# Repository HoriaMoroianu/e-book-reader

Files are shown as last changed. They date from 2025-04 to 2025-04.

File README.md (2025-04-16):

Moroianu Horia-Valentin

# OpenBook

## Diagrama bloc

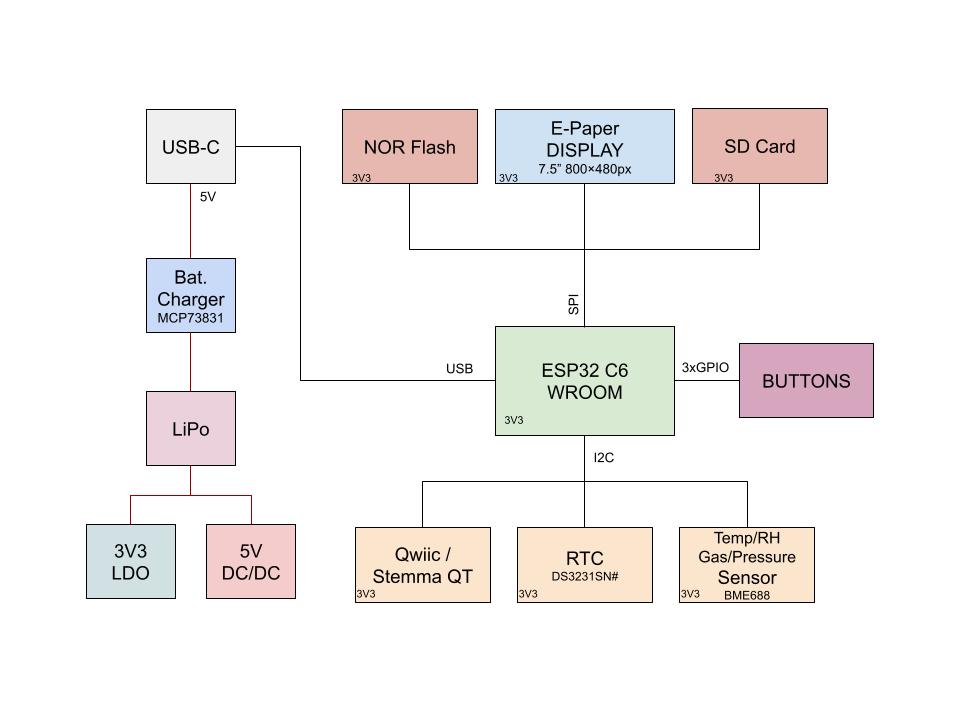
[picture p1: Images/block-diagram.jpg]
Diagrama bloc


## Prezentare Generala

Dispozitivul este construit in jurul microcontrolerului **ESP32-C6-WROOM-1-N8**, o componenta performanta ce ofera conectivitate Wi-Fi 6, Bluetooth 5 LE si o arhitectura RISC-V eficienta energetic. Acesta coordoneaza toate componentele periferice prin magistralele **SPI** si **I2C**.

Pentru masurarea timpului, este integrat un modul **RTC DS3231SN**, conectat prin I2C si semnale auxiliare pentru intreruperi si ceas. Pe aceeasi magistrala I2C functioneaza si senzorul **BME688**, responsabil pentru monitorizarea temperaturii, umiditatii, presiunii si compusilor din aer.

Datele pot fi stocate atat pe un **card SD** (SPI), cat si intr-o memorie **Flash NOR de 64MB**, utilizata pentru firmware. Afisajul grafic este realizat printr-un **ePaper Display**, conectat prin SPI, cu pini de control suplimentari pentru functionare eficienta.

Alimentarea este asigurata de un port **USB-C** cu protectie ESD, in combinatie cu un stabilizator **LDO** de 3.3V. Incarcarea bateriei Li-Po este gestionata de un circuit **MCP73831**, iar starea bateriei este monitorizata cu ajutorul unui **MAX17048**, controlat prin I2C.

Dispozitivul include si un conector **Qwiic/Stemma QT**, facilitand extinderea cu senzori compatibili I2C. Butoanele hardware permit controlul direct al functiilor de IO: resetare, boot si control.

## Conectivitate ESP32-C6

| Pin ESP32-C6 | Componenta Asociata | Functie |
|---|---|---|
| IO0 | RTC - DS3231SN | INT_RTC (Interrupt) |
| IO1 | RTC - DS3231SN | Semnal 32KHz |
| IO2 | SD Card, ePaper, Flash | SPI - MISO |
| IO3 | ePaper Display | EPD BUSY |
| IO4 | SD Card | SPI - CS |
| IO5 | ePaper Display | D/C (Data/Command) |
| IO6 | SD Card, ePaper, Flash | SPI - SCK |
| IO7 | SD Card, ePaper, Flash | SPI - MOSI |
| IO9 | Buton Boot | IO/BOOT |
| IO10 | ePaper Display | SPI - CS |
| IO11 | Flash | SPI - Flash CS |
| IO12 | USB | USB D− |
| IO13 | USB | USB D+ |
| IO15 | Buton CHANGE | IO/CHANGE |
| IO16 | Testpad | UART TX Debugg |
| IO17 | Testpad | UART RX Debugg |
| IO18 | RTC - DS3231SN | RTC Reset |
| IO19 | BME688 | I2C power line |
| IO20 | ePaper Display | EPD Power supply |
| IO21 | RTC, BME688, Qwiic | I2C - SDA |
| IO22 | RTC, BME688, Qwiic | I2C - SCL |
| IO23 | ePaper Display | Reset |
| EN | Buton Reset | IO/RESET |
| 3V3 | Toate modulele | Alimentare 3.3V |
| GND | Toate modulele | Masa |

## BOM

| Componenta | Sursa | Datasheet | Descriere |
| --- | --- | --- | --- |
| XC6220A331MR-G | [Product Page](https://ro.mouser.com/ProductDetail/Torex-Semiconductor/XC6220A331MR-G?qs=AsjdqWjXhJ8ZSWznL1J0gg%3D%3D) | [Datasheet](https://eu.mouser.com/datasheet/2/760/xc6220-3371556.pdf) | LDO regulator |
| W25Q512JVEIQ | [Product Page](https://ro.mouser.com/ProductDetail/Winbond/W25Q512JVEIQ?qs=l7cgNqFNU1jw6svr3at6tA%3D%3D) | [Datasheet](https://ro.mouser.com/datasheet/2/949/Winbond_W25Q512JV_Datasheet-3240039.pdf) | Nor flash |
| USBLC6-2SC6Y | [Product Page](https://ro.mouser.com/ProductDetail/STMicroelectronics/USBLC6-2SC6Y?qs=gNDSiZmRJS%2FOgDexvXkdow%3D%3D) | [Datasheet](https://ro.mouser.com/datasheet/2/389/usblc6_2sc6y-1852505.pdf) | USB ESD prot |
| SI1308EDL-T1-GE3 | [Product Page](https://ro.mouser.com/ProductDetail/Vishay-Semiconductors/SI1308EDL-T1-GE3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) | [Datasheet](https://www.vishay.com/docs/63399/si1308edl.pdf) | MOSFET |
| USB4110-GF-A | [Product Page](https://ro.mouser.com/ProductDetail/GCT/USB4110-GF-A?qs=KUoIvG%2F9IlYiZvIXQjyJeA%3D%3D) | [Datasheet](https://ro.mouser.com/datasheet/2/837/GCT_USB4110_Product_Drawing___20k_cycles-3455479.pdf) | USB C |
| PRT-14417 | [Product Page](https://ro.mouser.com/ProductDetail/SparkFun/PRT-14417?qs=wd5RIQLrsJhgdz%2FpmZ%2F3GQ%3D%3D) | [Datasheet](https://ro.mouser.com/datasheet/2/813/Qwiic_Connector_Datasheet-1223982.pdf) | Qwiic |
| PGB1010603MR | [Product Page](https://ro.mouser.com/ProductDetail/Littelfuse/PGB1010603MR?qs=gu7KAQ731URLg4GSnNNN7Q%3D%3D) | [Datasheet](https://www.littelfuse.com/assetdocs/pulseguard-esd-suppressors-pgb1-datasheet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) | ESD prot diode |
| MBR0530-TP | [Product Page](https://ro.mouser.com/ProductDetail/Micro-Commercial-Components-MCC/MBR0530-TP?qs=KFo7JewZbUECRHkxGanrdg%3D%3D) | [Datasheet](https://ro.mouser.com/datasheet/2/258/MBR0520_MBR0580_SOD123_-2492194.pdf) | Schottky diode |
| MAX17048G+T10 | [Product Page](https://ro.mouser.com/ProductDetail/Analog-Devices-Maxim-Integrated/MAX17048G%2bT10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) | [Datasheet](https://ro.mouser.com/datasheet/2/609/MAX17048_MAX17049-3469099.pdf) | Battery Management |
| FH34SRJ-24S-0.5SH(99) | [Product Page](https://ro.mouser.com/ProductDetail/Hirose-Connector/FH34SRJ-24S-0.5SH99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) | [Datasheet](https://ro.mouser.com/datasheet/2/185/FH34SRJ_24S_0_5SH_99__CL0580_1255_6_99_2DDrawing_0-1615044.pdf) | EPD connector |
| MCP73831-2ACI/MC | [Product Page](https://ro.mouser.com/ProductDetail/Microchip-Technology/MCP73831-2ACI-MC?qs=hH%252BOa0VZEiBneYTVdpuVdg%3D%3D) | [Datasheet](https://ro.mouser.com/datasheet/2/268/MCP73831_Family_Data_Sheet_DS20001984H-3441711.pdf) | Battery controller |
| BME688 | [Product Page](https://ro.mouser.com/ProductDetail/Bosch-Sensortec/BME688?qs=IS%252B4QmGtzzqQoVDscqwx3A%3D%3D) | [Datasheet](https://ro.mouser.com/datasheet/2/783/bst_bme688_fl000-2307034.pdf) | Sensor |
| SD0805S020S1R0 | [Product Page](https://ro.mouser.com/ProductDetail/KYOCERA-AVX/SD0805S020S1R0?qs=jCA%252BPfw4LHbpkAoSnwrdjw%3D%3D) | [Datasheet](https://ro.mouser.com/datasheet/2/40/schottky-3165252.pdf) | Schottky diode |
| B72540T0300K062 | [Product Page](https://ro.mouser.com/ProductDetail/EPCOS-TDK/B72540T0300K062?qs=dEfas%2FXlABK4d0Dv0OnYYg%3D%3D) | [Datasheet](https://www.tdk-electronics.tdk.com/inf/75/db/CTVS_14/Surge_protection_series.pdf) | Varistor |
| ESP32-C6-WROOM-1-N8 | [Product Page](https://ro.mouser.com/ProductDetail/Espressif-Systems/ESP32-C6-WROOM-1-N8?qs=8Wlm6%252BaMh8ST02Gmwp74cw%3D%3D) | [Datasheet](https://ro.mouser.com/datasheet/2/891/Espressif_ESP32_C6_WROOM_1__Datasheet_V0_1_PRELIMI-3239987.pdf) | ESP32 |
| DS3231SN# | [Product Page](https://ro.mouser.com/ProductDetail/Analog-Devices-Maxim-Integrated/DS3231SN?qs=1eQvB6Dk1vhUlr8%2FOrV0Fw%3D%3D) | [Datasheet](https://ro.mouser.com/datasheet/2/609/DS3231-3421123.pdf) | RTC |
| CPH3225A | [Product Page](https://ro.mouser.com/ProductDetail/Seiko-Semiconductors/CPH3225A?qs=3etwrb1wR%252BhUOph6lAO7eg%3D%3D) | [Datasheet](https://ro.mouser.com/datasheet/2/360/Seiko_Instruments_MicroBattery_E_20230330_2024Jan_-3561061.pdf) | Supercap |
| EVQ-P4MB3K | [Product Page](https://ro.mouser.com/ProductDetail/Panasonic/EVQ-P4MB3K?qs=0aNVN3t2tDvlcmyoDZjvlA%3D%3D) | [Datasheet](https://4donline.ihs.com/images/VipMasterIC/IC/PANA/PANA-S-A0000771493/PANA-S-A0000771493-1.pdf) | Buttons |
| BD5229G-TR | [Product Page](https://ro.mouser.com/ProductDetail/ROHM-Semiconductor/BD5229G-TR?qs=4kLU8WoGk0vvnhrrYwdszw%3D%3D) | [Datasheet](https://fscdn.rohm.com/en/products/databook/datasheet/ic/power/voltage_detector/bd52xxg-e.pdf) | Voltage detector |
| 744043680 | [Product Page](https://ro.mouser.com/ProductDetail/Wurth-Elektronik/744043680?qs=PGXP4M47uW6VkZq%252BkzjrHA%3D%3D) | [Datasheet](https://www.we-online.com/components/products/datasheet/744043680.pdf) | Inductor |
| R0402 | [Product Page](https://ro.mouser.com/c/passive-components/resistors/smd-resistors-chip-resistors/?case%20code%20-%20in=0402) | [Datasheet](https://www.vishay.com/docs/28700/mcx0x0xpre.pdf) | Resistor 0402 |
| DMG2305UX-7 | [Product Page](https://ro.mouser.com/ProductDetail/Diodes-Incorporated/DMG2305UX-7?qs=L1DZKBg7t5F%2FNBHrjfxC%252Bg%3D%3D) | [Datasheet](https://www.diodes.com/assets/Datasheets/DMG2305UX.pdf) | MOSFET |
| 112A-TAAR-R03 | [Product Page](https://store.comet.srl.ro/Catalogue/Product/43497/?mark=2) | [Datasheet](https://www.attend.com.tw/data/download/file/112A-TAAR-R03_Spec.pdf) | SD Socket |
| T491B107M006AT | [Product Page](https://ro.mouser.com/ProductDetail/KEMET/T491B107M006AT?qs=U312oeP%2FpiHOgyk6KO2m0g%3D%3D) | [Datasheet](https://ro.mouser.com/datasheet/2/447/KEM_T2005_T491-3316937.pdf) | Tantalum Capacitor |
| LSM0603472V | [Product Page](https://ro.mouser.com/ProductDetail/VCC/LSM0603472V?qs=%252BEew9%252B0nqrBygsW37Z2ISQ%3D%3D) | [Datasheet](https://ro.mouser.com/datasheet/2/423/LSM0603472V_(1)-1379786.pdf) | LED |
| C0402C475K8PACTU | [Product Page](https://ro.mouser.com/c/passive-components/capacitors/ceramic-capacitors/mlccs-multilayer-ceramic-capacitors/multilayer-ceramic-capacitors-mlcc-smd-smt/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) | [Datasheet](https://ro.mouser.com/datasheet/2/447/KEM_C1006_X5R_SMD-3316465.pdf) | Capacitor 0402 |

## Imagini
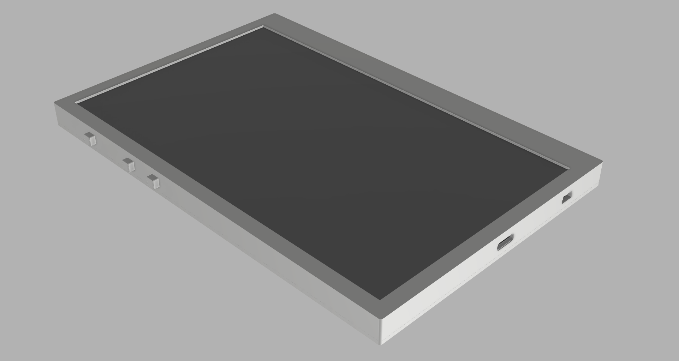
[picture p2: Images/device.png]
device

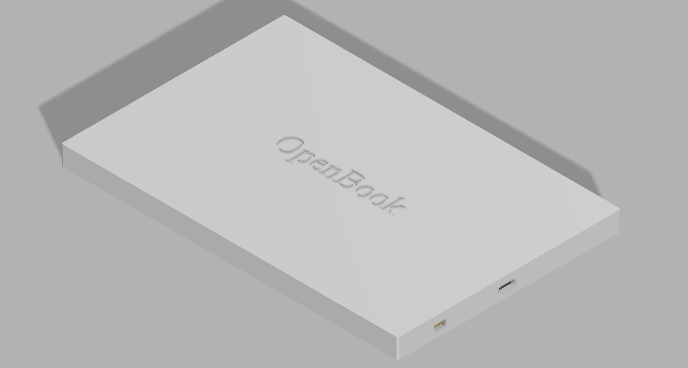
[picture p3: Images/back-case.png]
back case

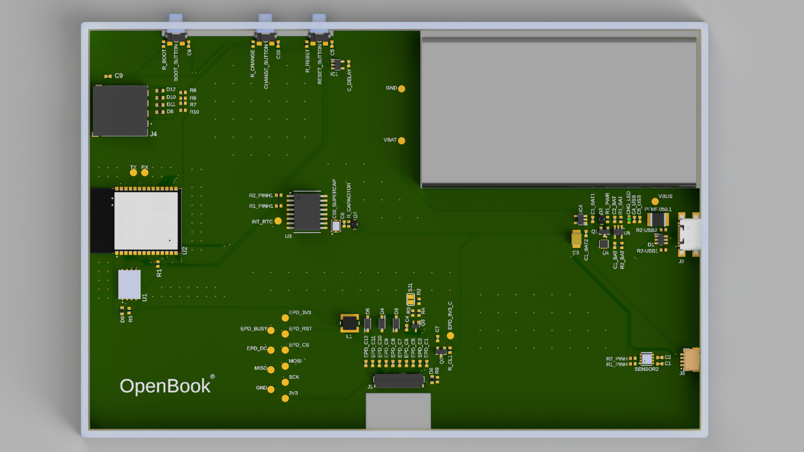
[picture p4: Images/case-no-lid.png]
case no lid

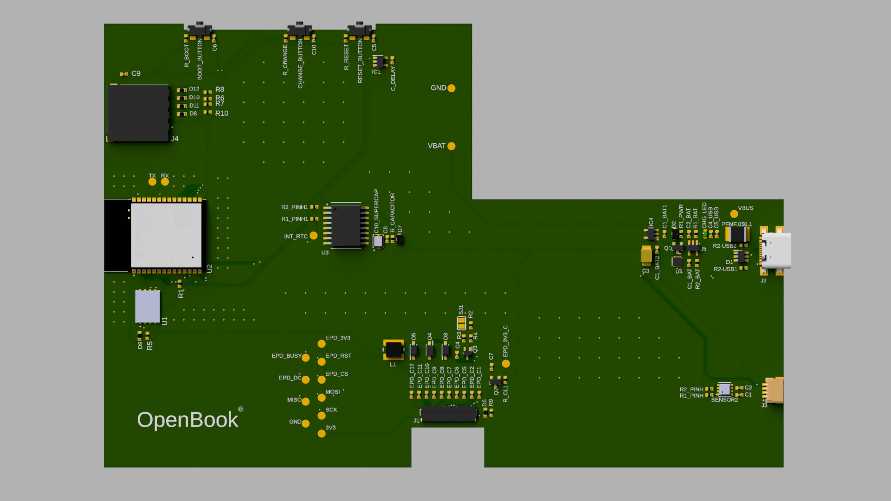
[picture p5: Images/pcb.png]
pcb

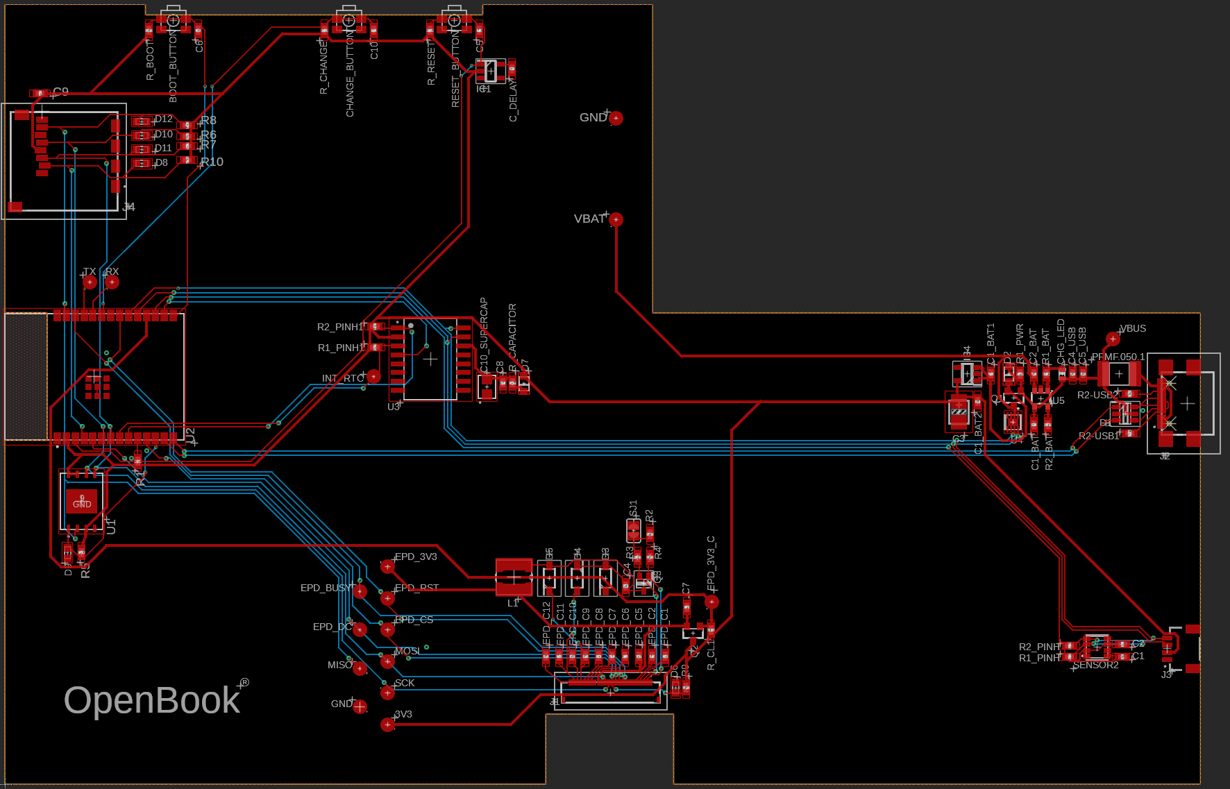
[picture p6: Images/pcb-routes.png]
pcb-routes

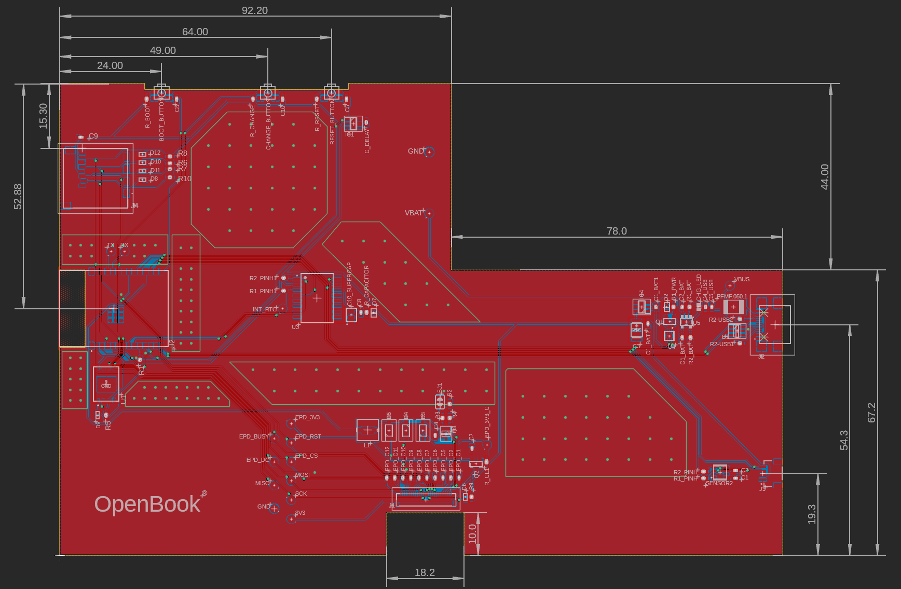
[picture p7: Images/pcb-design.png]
pcb-design


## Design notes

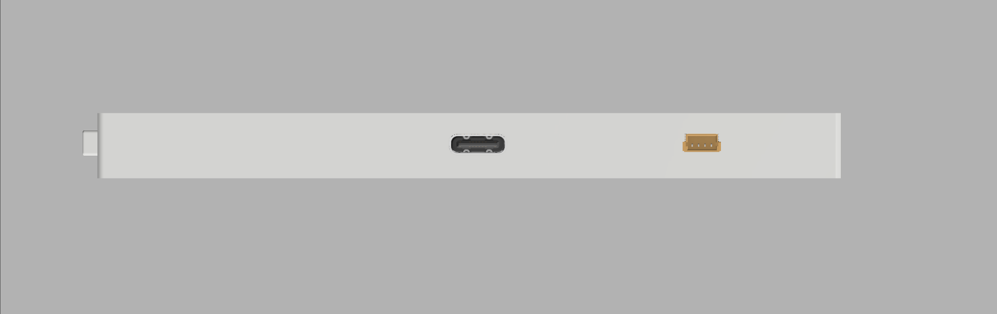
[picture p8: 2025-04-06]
Images/ports.png

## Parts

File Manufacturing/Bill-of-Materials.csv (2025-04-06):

Qty | Value | Device | Package | Parts | Description | ARROW_PART_NUMBER | ARROW_PRICE-STOCK | AVAILABILITY | BME688 | CENTROID_NOT_SPECIFIED | CHECK_PRICES | COPYRIGHT | DATASHEET | DESCRIPTION | DIGIKEY_DESCRIPTION | DIGIKEY_PART_NUMBER | DMG2305UX-7 | HEIGHT | LEAD_FREE | MANUFACTURER_NAME | MANUFACTURER_PART_NUMBER | MCP73831 | MF | MFR_NAME | MOUSER_PART_NUMBER | MOUSER_PRICE-STOCK | MOUSER_TESTING_PART_NUMBER | MOUSER_TESTING_PRICE-STOCK | MP | MPN | PACKAGE | POPULARITY | PREFIX | PRICE | PROD_ID | PURCHASE-URL | ROHS | SD0805S020S1R0 | SNAPEDA_LINK | SPICEMODEL | SPICEPREFIX | TANT | TEMPERATURE_RANGE_HIGH | TEMPERATURE_RANGE_LOW | TP_SIGNAL_NAME | VAL | VALUE
1 |  | ADAFRUIT_LEDCHIP-LED0603 | ADAFRUIT_CHIP-LED0603 | CHG_LED | LED
1 |  | SJ | SJ | SJ1 | SMD solder JUMPER |  |  |  |  |  |  |  |  |  |  |  |  |  |  |  |  |  |  |  |  |  |  |  |  |  |  | 3
1 | 0.1uF/50V | EAGLE-LTSPICE_CC0402 | EAGLE-LTSPICE_C0402 | EPD_C5 | CAPACITOR, European symbol |  |  |  |  |  |  |  |  |  |  |  |  |  |  |  |  |  |  |  |  |  |  |  |  |  |  |  |  |  |  |  |  |  |  | NONE | C
1 | 0.47 | ESP32_WROVER_EAGLE-LTSPICE_RR0402 | ESP32_WROVER_EAGLE-LTSPICE_R0402 | R3 | RESISTOR, European symbol |  |  |  |  |  |  |  |  |  |  |  |  |  |  |  |  |  |  |  |  |  |  |  |  |  |  |  |  |  |  |  |  |  |  | NONE | R
1 | 100k | ESP32_WROVER_EAGLE-LTSPICE_RR0402 | ESP32_WROVER_EAGLE-LTSPICE_R0402 | R1_PWRUSB | RESISTOR, European symbol |  |  |  |  |  |  |  |  |  |  |  |  |  |  |  |  |  |  |  |  |  |  |  |  |  |  |  |  |  |  |  |  |  |  | NONE | R
8 | 100nF | EAGLE-LTSPICE_CC0402 | EAGLE-LTSPICE_C0402 | C1, C2, C4_USB, C6, C8, C9, C10, C_DELAY | CAPACITOR, European symbol |  |  |  |  |  |  |  |  |  |  |  |  |  |  |  |  |  |  |  |  |  |  |  |  |  |  |  |  |  |  |  |  |  |  | NONE | C
1 | 100uF | RCL_CPOL-EUCT3528 | RCL_CT3528 | C3 | POLARIZED CAPACITOR, European symbol |  |  |  |  |  |  |  |  |  |  |  |  |  |  |  |  |  |  |  |  |  |  |  |  |  |  | 0 |  |  |  |  |  |  |  |  | C
16 | 10k | ESP32_WROVER_EAGLE-LTSPICE_RR0402 | ESP32_WROVER_EAGLE-LTSPICE_R0402 | R1, R1_PINH, R1_PINH1, R2_PINH, R2_PINH1, R4, R5, R6, R7, R8, R9, R10, R_BOOT, R_CHANGE, R_CL1, R_RESET | RESISTOR, European symbol |  |  |  |  |  |  |  |  |  |  |  |  |  |  |  |  |  |  |  |  |  |  |  |  |  |  |  |  |  |  |  |  |  |  | NONE | R
1 | 10uF | EAGLE-LTSPICE_CC0402 | EAGLE-LTSPICE_C0402 | C7 | CAPACITOR, European symbol |  |  |  |  |  |  |  |  |  |  |  |  |  |  |  |  |  |  |  |  |  |  |  |  |  |  |  |  |  |  |  |  |  |  | NONE | C
1 | 112A-TAAR-R03_ATTEND | 112A-TAAR-R03_ATTEND | 112ATAARR03ATTEND | J4 | Micro SD Card Socket, Push-Push Type, Top Mount, SMT, H=1.83mm, 10u |  |  |  |  |  |  |  |  | Micro SD Card Socket | Push-Push Type | Top Mount | SMT | H=1.83mm | 10u |  |  |  | 1.9mm |  | ATTEND | 112A-TAAR-R03 ATTEND
1 | 15 | ESP32_WROVER_EAGLE-LTSPICE_RR0402 | ESP32_WROVER_EAGLE-LTSPICE_R0402 | R_CAPACITOR | RESISTOR, European symbol |  |  |  |  |  |  |  |  |  |  |  |  |  |  |  |  |  |  |  |  |  |  |  |  |  |  |  |  |  |  |  |  |  |  | NONE | R
1 | 1uF | EAGLE-LTSPICE_CC0402 | EAGLE-LTSPICE_C0402 | C5 | CAPACITOR, European symbol |  |  |  |  |  |  |  |  |  |  |  |  |  |  |  |  |  |  |  |  |  |  |  |  |  |  |  |  |  |  |  |  |  |  | NONE | C
9 | 1uF/50V | EAGLE-LTSPICE_CC0402 | EAGLE-LTSPICE_C0402 | EPD_C1, EPD_C2, EPD_C6, EPD_C7, EPD_C8, EPD_C9, EPD_C10, EPD_C11, EPD_C12 | CAPACITOR, European symbol |  |  |  |  |  |  |  |  |  |  |  |  |  |  |  |  |  |  |  |  |  |  |  |  |  |  |  |  |  |  |  |  |  |  | NONE | C
1 | 2.2 | ESP32_WROVER_EAGLE-LTSPICE_RR0402 | ESP32_WROVER_EAGLE-LTSPICE_R0402 | R2 | RESISTOR, European symbol |  |  |  |  |  |  |  |  |  |  |  |  |  |  |  |  |  |  |  |  |  |  |  |  |  |  |  |  |  |  |  |  |  |  | NONE | R
1 | 200 | ESP32_WROVER_EAGLE-LTSPICE_RR0402 | ESP32_WROVER_EAGLE-LTSPICE_R0402 | R1_BAT | RESISTOR, European symbol |  |  |  |  |  |  |  |  |  |  |  |  |  |  |  |  |  |  |  |  |  |  |  |  |  |  |  |  |  |  |  |  |  |  | NONE | R
2 | 20V/4.2A/52mO/1.4W | ESP32_WROVER_SPARKFUN-DISCRETESEMI_MOSFET_PCH-DMG2305UX-7 | ESP32_WROVER_SPARKFUN-DISCRETESEMI_SOT23-3 | Q1, Q2 | P-channel MOSFETs |  |  |  |  |  |  |  |  |  |  |  |  |  |  |  |  |  |  |  |  |  |  |  |  |  |  |  |  |  | TRAN-14388 |  |  |  |  |  |  |  |  |  |  |  | 20V/4.2A/52mO/1.4W
1 | 2k | ESP32_WROVER_EAGLE-LTSPICE_RR0402 | ESP32_WROVER_EAGLE-LTSPICE_R0402 | R2_BAT | RESISTOR, European symbol |  |  |  |  |  |  |  |  |  |  |  |  |  |  |  |  |  |  |  |  |  |  |  |  |  |  |  |  |  |  |  |  |  |  | NONE | R
5 | 4.7uF | EAGLE-LTSPICE_CC0402 | EAGLE-LTSPICE_C0402 | C1_BAT, C1_BAT1, C1_BAT2, C2_BAT, C5_USB | CAPACITOR, European symbol |  |  |  |  |  |  |  |  |  |  |  |  |  |  |  |  |  |  |  |  |  |  |  |  |  |  |  |  |  |  |  |  |  |  | NONE | C
1 | 4.7uF/25V | EAGLE-LTSPICE_CC0402 | EAGLE-LTSPICE_C0402 | C4 | CAPACITOR, European symbol |  |  |  |  |  |  |  |  |  |  |  |  |  |  |  |  |  |  |  |  |  |  |  |  |  |  |  |  |  |  |  |  |  |  | NONE | C
2 | 5K1 | ESP32_WROVER_EAGLE-LTSPICE_RR0402 | ESP32_WROVER_EAGLE-LTSPICE_R0402 | R2-USB1, R2-USB2 | RESISTOR, European symbol |  |  |  |  |  |  |  |  |  |  |  |  |  |  |  |  |  |  |  |  |  |  |  |  |  |  |  |  |  |  |  |  |  |  | NONE | R
1 | 744043680IND_4828-WE-TPC_WRE | 744043680IND_4828-WE-TPC_WRE | IND_4828-WE-TPC_WRE | L1 |  |  |  |  |  |  |  | Copyright (C) 2024 Ultra Librarian. All rights reserved. |  |  |  |  |  |  |  |  | 744043680 |  |  | Wurth Electronics |  |  |  |  |  |  |  |  |  |  |  |  |  |  |  |  |  |  |  |  |  | 68uH
1 | BD5229G-TR | BD5229G-TR | SOT95P280X125-5N | IC1 | Voltage Detector with Adjustable Delay Time: CMOS processes are utilized to develop high precision, low current consumption CMOS reset ICs that allow arbitrary setting of the delay time. The extensive lineup includes both Nch Open Drain and CMOS output types in a wide range of detection voltages (from 2.3V to 6.0V, in 0.1V steps), enabling selection of the ideal solution based on customer requirements. In addition, the entire series is of course both lead-free and RoHS-compliant. |  |  |  |  |  |  |  |  | Voltage Detector with Adjustable Delay Time: CMOS processes are utilized to develop high precision | low current consumption CMOS reset ICs that allow arbitrary setting of the delay time. The extensive lineup includes both Nch Open Drain and CMOS output types in a wide range of detection voltages (from 2.3V to 6.0V | in 0.1V steps) | enabling selection of the ideal solution based on customer requirements. In addition | the entire series is of course both lead-free and RoHS-compliant. |  |  |  | 1.25mm |  | ROHM Semiconductor | BD5229G-TR |  |  |  | 755-BD5229G-TR | https://www.mouser.co.uk/ProductDetail/ROHM-Semiconductor/BD5229G-TR?qs=4kLU8WoGk0vvnhrrYwdszw%3D%3D
3 | BUTTON_CUSYOMV1 | BUTTON_CUSYOMV1 | MYBUTTON | BOOT_BUTTON, CHANGE_BUTTON, RESET_BUTTON
1 | CPH3225A | CPH3225A | CAPCP3225X100N | C10_SUPERCAP | Cap 0.011F 3.3V 1210 Flat Check availability |  |  | Not in stock |  |  | https://www.snapeda.com/parts/CPH3225A/Seiko+Instruments/view-part/?ref=eda |  |  | 11 mF (EDLC) Supercapacitor 3.3 V 1210 (3225 Metric) - - |  |  |  |  |  |  |  |  | Seiko Instruments |  |  |  |  |  | CPH3225A |  | 1210 Seiko |  |  | None |  | https://www.snapeda.com/api/url_track_click_mouser/?unipart_id=562593&manufacturer=Seiko Instruments&part_name=CPH3225A&search_term=None |  |  | https://www.snapeda.com/parts/CPH3225A/Seiko+Instruments/view-part/?ref=snap
1 | DS3231SN# | DS3231SN# | SOIC127P1032X265-16N | U3 | Real Time Clock Serial 16-Pin SOIC W T/R Check availability |  |  | In Stock |  |  | https://www.snapeda.com/parts/DS3231SN%23/Analog+Devices/view-part/?ref=eda |  |  | Extremely Accurate I²C-Integrated RTC/TCXO/Crystal |  |  |  |  |  |  |  |  | Analog Devices |  |  |  |  |  | DS3231SN# |  | SOIC-16 Maxim |  |  | None |  | https://www.snapeda.com/api/url_track_click_mouser/?unipart_id=99048&manufacturer=Analog Devices&part_name=DS3231SN#&search_term=None |  |  | https://www.snapeda.com/parts/DS3231SN%23/Analog+Devices/view-part/?ref=snap
1 | ESP32-C6-WROOM-1-N8 | ESP32-C6-WROOM-1-N8 | XCVR_ESP32-C6-WROOM-1-N8 | U2 | Check availability |  |  | In Stock |  |  | https://www.snapeda.com/parts/ESP32-C6-WROOM-1-N8/Espressif+Systems/view-part/?ref=eda |  |  | Multiprotocol Modules ESP32-C6 module | Wi-Fi 6 in 2.4 GHz band | Bluetooth 5 | Zigbee 3.0 and Thread. ESP34-WROOM Compatible - ENGINEERING SAMPLE |  |  |  |  |  |  |  |  | Espressif Systems |  |  |  |  |  | ESP32-C6-WROOM-1-N8 |  | None |  |  | None |  |  |  |  | https://www.snapeda.com/parts/ESP32-C6-WROOM-1-N8/Espressif+Systems/view-part/?ref=snap
1 | ESP32C6_VARISTORCN1812 | ESP32C6_VARISTORCN1812 | ESP32C6_VARISTOR_CT/CN1812 | PFMF.050.1 | VARISTOR |  |  |  |  |  |  |  |  |  |  |  |  |  |  |  |  |  |  |  |  |  |  |  |  |  |  | 0
2 | ESP32_WROVER_AVX---SD0805S020S1R0_AVX_SD0805S020S1R0_0_0AVX_SD0805S020S1R0_0_0 | ESP32_WROVER_AVX---SD0805S020S1R0_AVX_SD0805S020S1R0_0_0AVX_SD0805S020S1R0_0_0 | ESP32_WROVER_AVX---SD0805S020S1R0_AVX_SD0805S020S1R0_0 | D2, D7 | Schottky Barrier Rectifier Diode |  |  |  |  | No |  |  | http://datasheets.avx.com/schottky.pdf |  | DIODE SCHOTTKY 20V 1A 0805 | 478-7800-1-ND |  |  | yes |  |  |  | AVX |  | 581-SD0805S020S1R0 |  |  |  |  |  | 0805 (2012 metric) |  | D |  |  |  | yes |  |  |  |  |  | +125°C | -55°C
1 | ESP32_WROVER_BME680_BME680 | ESP32_WROVER_BME680_BME680 | ESP32_WROVER_BME680_PSON80P300X300X100-8N | SENSOR2 | Integrated Environmental Unit |  |  | Unavailable |  |  |  |  |  | Integrated Environmental Unit |  |  |  |  |  |  |  |  | Bosch Sensortec |  |  |  |  |  | BME680 |  | LGA-8 Bosch Tools |  |  | None
1 | ESP32_WROVER_SPARKFUN-IC-POWER_MCP73831 | ESP32_WROVER_SPARKFUN-IC-POWER_MCP73831 | ESP32_WROVER_SPARKFUN-IC-POWER_SOT23-5 | U5 | MCP73831T Li-Ion, Li-Pol Controller |  |  |  |  |  |  |  |  |  |  |  |  |  |  |  |  |  |  |  |  |  |  |  |  |  |  |  |  |  | IC-09995
1 | FH34SRJ-24S-0.5SH_99_ | FH34SRJ-24S-0.5SH_99_ | FH34SRJ24S05SH99 | J1 | (0.50mm) Surface Mount, Right Angle |  |  |  |  |  |  |  |  | 24 Position FFC | FPC Connector Contacts | (0.50mm) Surface Mount | Right Angle |  |  |  | 1.1mm |  | Hirose | FH34SRJ-24S-0.5SH(99) |  |  |  | 798-FH34SRJ24S05SH99 | https://www.mouser.co.uk/ProductDetail/Hirose-Connector/FH34SRJ-24S-0.5SH99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
1 | MAX17048G+T10 | MAX17048G+T10 | SON50P200X200X80-9N | U4 | Check availability |  |  | In Stock |  |  | https://www.snapeda.com/parts/MAX17048G+T10/Analog+Devices/view-part/?ref=eda |  |  | 3µA 1-Cell/2-Cell Fuel Gauge with ModelGauge |  |  |  |  |  |  |  |  | Analog Devices |  |  |  |  |  | MAX17048G+T10 |  | TDFN-8 Maxim |  |  | None |  | https://www.snapeda.com/api/url_track_click_mouser/?unipart_id=329239&manufacturer=Analog Devices&part_name=MAX17048G+T10&search_term=None |  |  | https://www.snapeda.com/parts/MAX17048G+T10/Analog+Devices/view-part/?ref=snap
3 | MBR0530 | MBR0530 | SOD3716X135N | D3, D4, D5 | ON SEMICONDUCTOR - MBR0530 - DIODE, SCHOTTKY, 0.5A, 30V, SOD-123 |  |  | In Stock |  |  | https://www.snapeda.com/parts/MBR0530/Onsemi/view-part/?ref=eda |  |  | Diode Schottky 30 V 500mA Surface Mount SOD-123 |  |  |  |  |  |  |  |  | ON Semiconductor |  |  |  |  |  | MBR0530 |  | SOD-123-2 ON Semiconductor |  |  | None |  | https://www.snapeda.com/api/url_track_click_mouser/?unipart_id=179458&manufacturer=ON Semiconductor&part_name=MBR0530&search_term=None |  |  | https://www.snapeda.com/parts/MBR0530/Onsemi/view-part/?ref=snap
6 | PGB1010603MR | PGB1010603MR | DIOC1608X36N | D6, D8, D9, D10, D11, D12 | Check availability |  |  | In Stock |  |  | https://www.snapeda.com/parts/PGB1010603MR/Littelfuse/view-part/?ref=eda |  |  | 150V (Typ) Clamp - Ipp Tvs Diode Surface Mount 0603 (1608 Metric) |  |  |  |  |  |  |  |  | Littelfuse Inc. |  |  |  |  |  | PGB1010603MR |  | 0603 Littelfuse Inc. |  |  | None |  | https://www.snapeda.com/api/url_track_click_mouser/?unipart_id=5659453&manufacturer=Littelfuse Inc.&part_name=PGB1010603MR&search_term=None |  |  | https://www.snapeda.com/parts/PGB1010603MR/Littelfuse/view-part/?ref=snap
1 | QWIIC_RIGHT_ANGLE | QWIIC_CONNECTORJS-1MM | JST04_1MM_RA | J3 | SparkFun I2C Standard Qwiic Connector |  |  |  |  |  |  |  |  |  |  |  |  |  |  |  |  |  |  |  |  |  |  |  |  |  |  |  |  |  | CONN-13694 |  |  |  |  |  |  |  |  |  |  |  | QWIIC_RIGHT_ANGLE
1 | SAMACSYS_PARTS_USB4110-GF-A | SAMACSYS_PARTS_USB4110-GF-A | SAMACSYS_PARTS_USB4110GFA | J2 | CONN USB 2.0 TYPE-C R/A SMT |  |  |  |  |  |  |  |  | CONN USB 2.0 TYPE-C R/A SMT |  |  |  | 3.26mm |  | GCT (GLOBAL CONNECTOR TECHNOLOGY) | USB4110-GF-A |  |  |  | 640-USB4110-GF-A | https://www.mouser.co.uk/ProductDetail/GCT/USB4110-GF-A?qs=KUoIvG%2F9IlYiZvIXQjyJeA%3D%3D
1 | SI1308EDL-T1-GE3 | SI1308EDL-T1-GE3 | SOT65P210X110-3N | Q3 | MOSFET N-Ch 30V 1.5A TrenchFET SC70 Vishay Si1308EDL-T1-GE3 N-channel MOSFET Transistor, 1.5 A, 30 V, 3-Pin SC-70 |  |  | In Stock |  |  | https://www.snapeda.com/parts/SI1308EDL-T1-GE3/Vishay+Siliconix/view-part/?ref=eda |  |  | Si1308EDL-T1-GE3 N-channel MOSFET Transistor | 1.5 A | 30 V | 3-Pin SC-70 | Siliconix / Vishay SI1308EDL-T1-GE3 |  |  |  |  |  |  |  |  | Vishay Siliconix |  |  |  |  |  | SI1308EDL-T1-GE3 |  | SOT-323 Vishay Semiconductor |  |  | None |  | https://www.snapeda.com/api/url_track_click_mouser/?unipart_id=274603&manufacturer=Vishay Siliconix&part_name=SI1308EDL-T1-GE3&search_term=None |  |  | https://www.snapeda.com/parts/SI1308EDL-T1-GE3/Vishay+Siliconix/view-part/?ref=snap
17 | TPTP20R | TPTP20R | TP20R | TP1, TP2, TP3, TP4, TP5, TP6, TP7, TP8, TP9, TP10, TP11, TP12, TP13, TP14, TP15, TP16, TP17 | Test pad |  |  |  |  |  |  |  |  |  |  |  |  |  |  |  |  |  |  |  |  |  |  |  |  |  |  | 2
1 | USBLC6-2SC6Y | USBLC6-2SC6Y | SOT95P280X145-6N | D1 | Low Cap. ESD Protection Auto SOT-23-6 STMicroelectronics USBLC6-2SC6Y, Dual Uni-Directional TVS Diode Array, 6-Pin SOT-23 |  |  | In Stock |  |  | https://www.snapeda.com/parts/USBLC6-2SC6Y/STMicroelectronics/view-part/?ref=eda |  |  | 17V Clamp 5A (8/20µs) Ipp Tvs Diode Surface Mount SOT-23-6 |  |  |  |  |  |  |  |  | STMicroelectronics |  |  |  |  |  | USBLC6-2SC6Y |  | SOT-23-6 STMicroelectronics |  |  | None |  |  |  |  | https://www.snapeda.com/parts/USBLC6-2SC6Y/STMicroelectronics/view-part/?ref=snap
1 | W25Q512JVEIQ | W25Q512JVEIQ | SON127P600X800X80-9N | U1 | Check availability |  |  | In Stock |  |  | https://www.snapeda.com/parts/W25Q512JVEIQ/Winbond+Electronics/view-part/?ref=eda |  |  | FLASH - NOR Memory IC 512Mb (64M x 8) SPI - Quad I/O 133 MHz 8-WSON (8x6) |  |  |  |  |  |  |  |  | Winbond Electronics |  |  |  |  |  | W25Q512JVEIQ |  | Package |  |  | None |  |  |  |  | https://www.snapeda.com/parts/W25Q512JVEIQ/Winbond+Electronics/view-part/?ref=snap
1 | XC6220A331MR-G | XC6220A331MR-G | SOT95P280X120-5N | IC4 | LDO Voltage Regulators |  |  |  |  |  |  |  |  | LDO Voltage Regulators |  |  |  | 1.2mm |  | Torex | XC6220A331MR-G |  |  |  | 865-XC6220A331MR-G | https://www.mouser.co.uk/ProductDetail/Torex-Semiconductor/XC6220A331MR-G?qs=AsjdqWjXhJ8ZSWznL1J0gg%3D%3D

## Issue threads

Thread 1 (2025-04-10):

Trebuie adaugate informatii in README.md

branistecristian, 2025-04-10:
**README** trebuie să conțină minim:
- O diagramă bloc cu toate componentele proiectului vostru și cum sunt ele legate (model aici).
- Un **BOM** (Bill Of Materials) sub formă de tabel cu componentele sau modulele pe care le-ați folosit și link-uri către locul de unde le puteți procura (folosiți Mouser și Comet) și link către datasheet-ul lor.
- Descrierea în detaliu a funcționalității hardware (ce module, componente, senzori, etc. ați folosit, prin ce interfețe se leagă la microcontroller-ul vostru, specificații de comunicație, procesare, calcule de consum de energie și orice altceva considerați relevant).
- Descrieți în detaliu ce pini ai **ESP32-C6** sunt folosiți pentru fiecare componentă și de ce.
- Orice altceva considerați că ar fi relevant pentru review (design log, imagini cu randări ale PCB-ului, așezarea componentelor în carcasă etc.).

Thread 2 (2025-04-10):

Grosime PCB

branistecristian, 2025-04-10:
### PCB-ul este configurat in prezent cu o grosime de **1.6mm**, insa proiectul necesita o grosime de **1.0mm** pentru a se potrivi corect in carcasa

## Referinte
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

HoriaMoroianu, 2025-04-16:
Eroare la export

Closed 2025-04-16.

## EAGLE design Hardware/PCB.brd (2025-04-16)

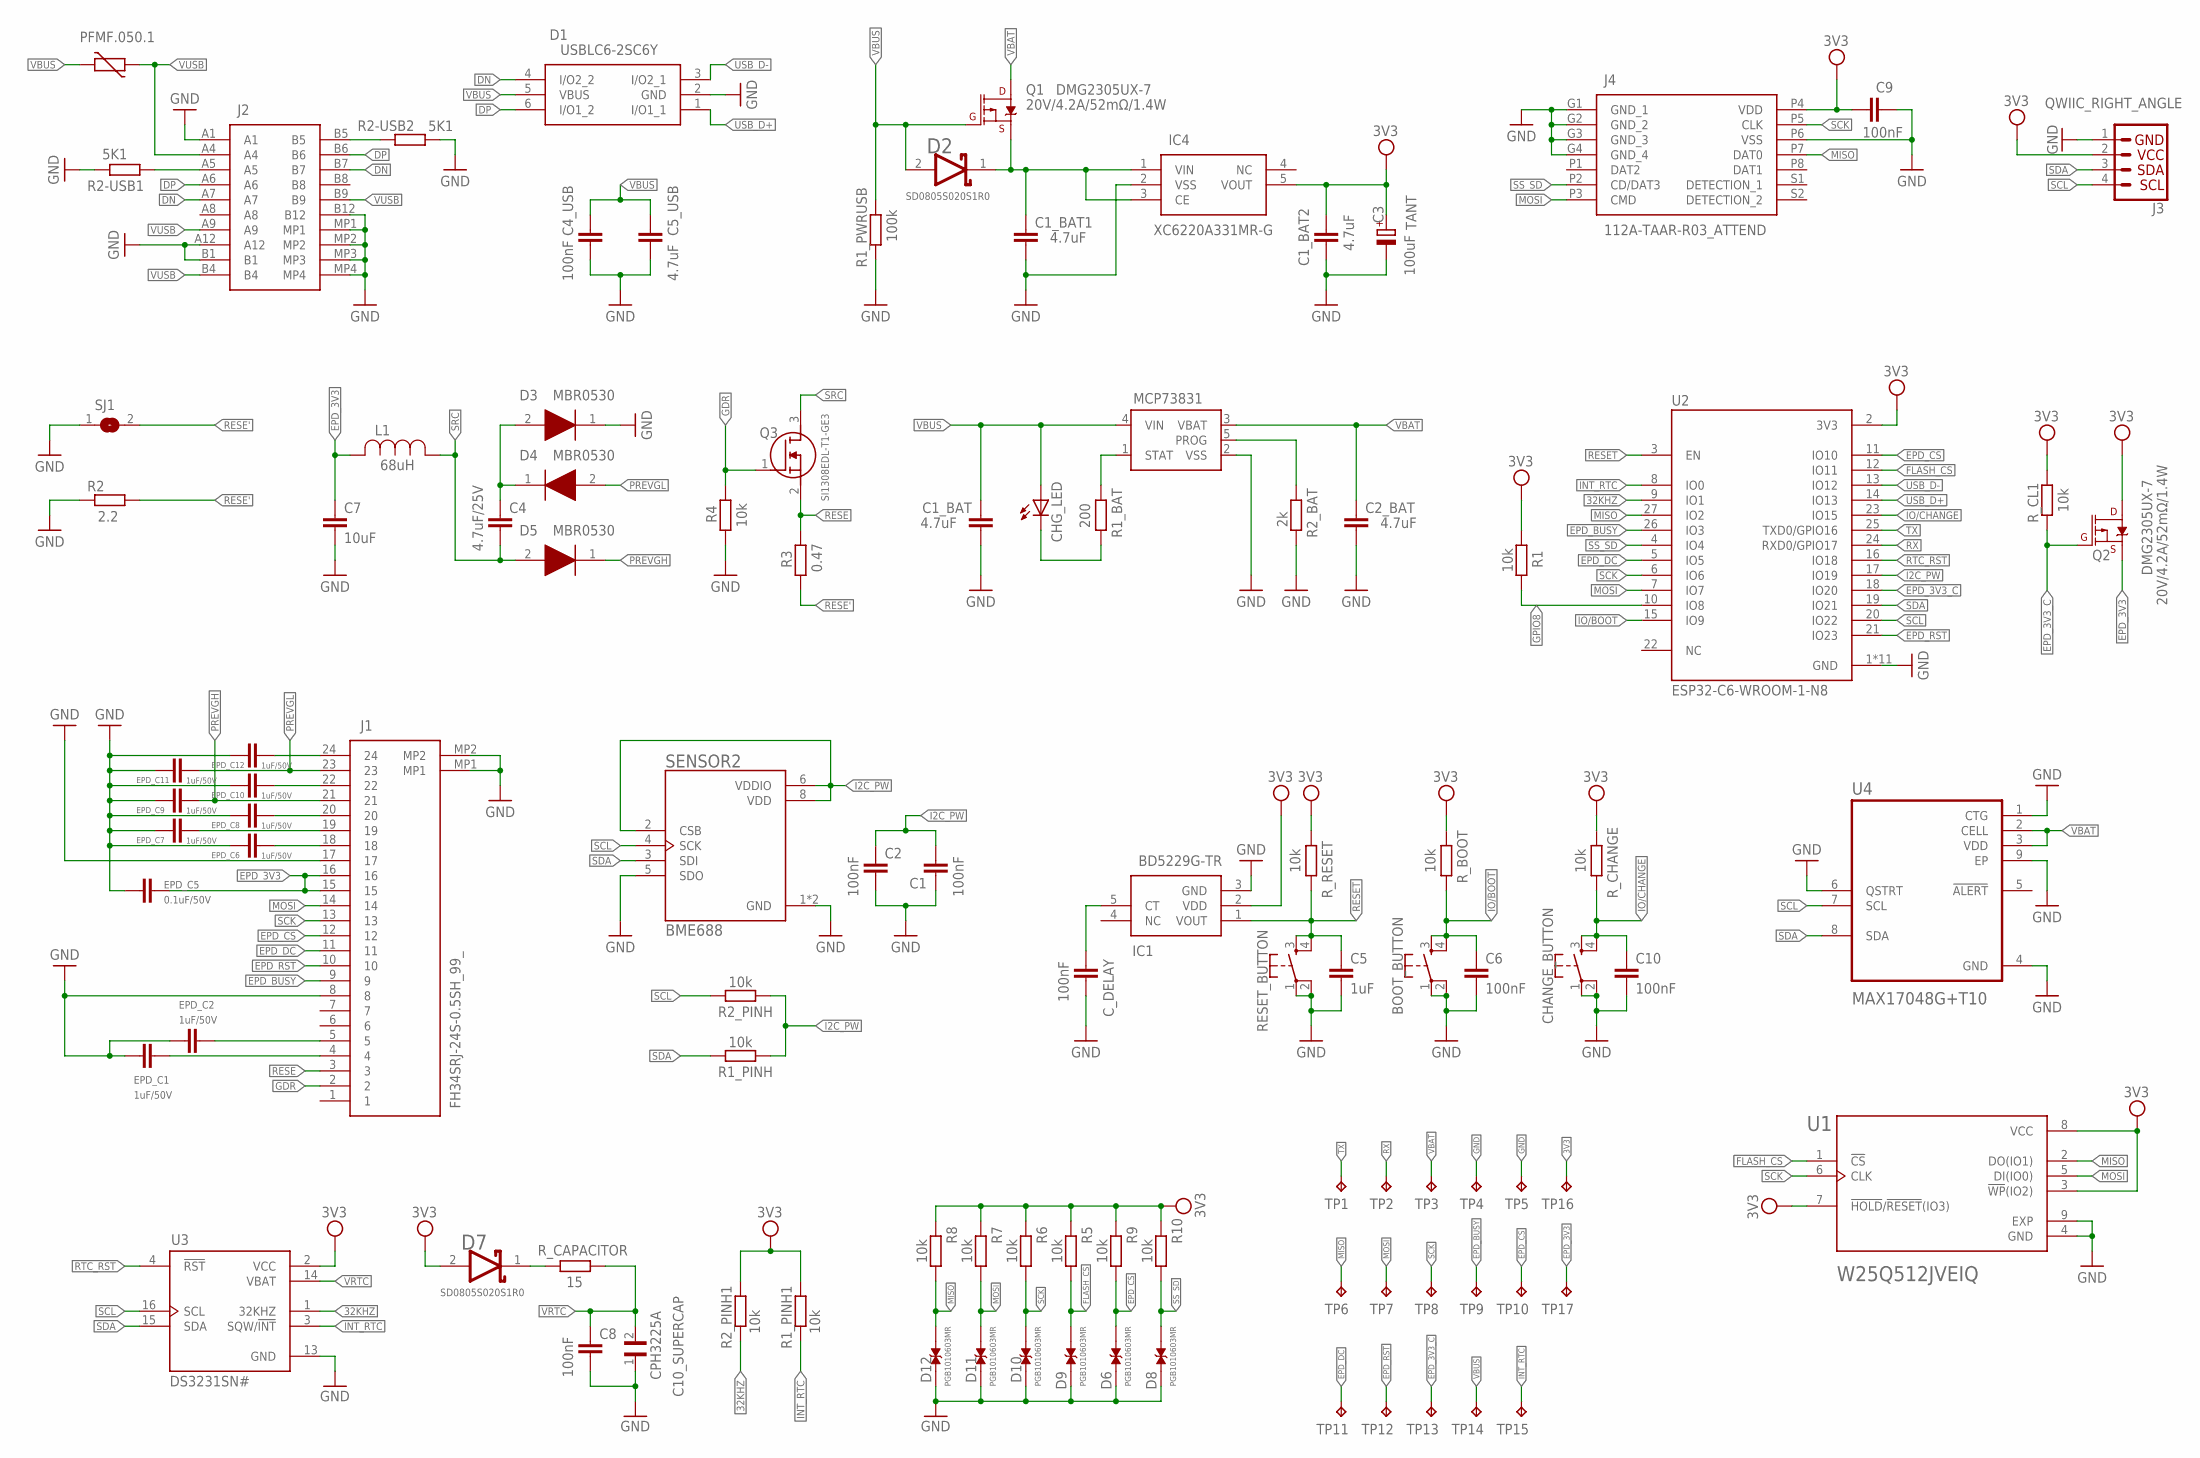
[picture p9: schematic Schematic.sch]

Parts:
BOOT_BUTTON: BUTTON_CUSYOMV1; MYBUTTON
C1, C2, C4_USB, C6, C8, C9, C10: 100nF; EAGLE-LTSPICE_C0402
C1_BAT, C1_BAT1, C1_BAT2, C2_BAT, C5_USB: 4.7uF; EAGLE-LTSPICE_C0402
C3: 100uF; RCL_CT3528
C4: 4.7uF/25V; EAGLE-LTSPICE_C0402
C5: 1uF; EAGLE-LTSPICE_C0402
C7: 10uF; EAGLE-LTSPICE_C0402
C10_SUPERCAP: CPH3225A; CAPCP3225X100N
CHANGE_BUTTON: BUTTON_CUSYOMV1; MYBUTTON
CHG_LED: ADAFRUIT_LEDCHIP-LED0603; ADAFRUIT_CHIP-LED0603
C_DELAY: 100nF; EAGLE-LTSPICE_C0402
D1: USBLC6-2SC6Y; SOT95P280X145-6N
D2, D7: ESP32_WROVER_AVX---SD0805S020S1R0_AVX_SD0805S020S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; ESP32_WROVER_AVX---SD0805S020S1R0_AVX_SD0805S020S1R0_0
D3, D4, D5: MBR0530; SOD3716X135N
D6, D8, D9, D10, D11, D12: PGB1010603MR; DIOC1608X36N
EPD_C1, EPD_C2, EPD_C6, EPD_C7, EPD_C8, EPD_C9, EPD_C10, EPD_C11, EPD_C12: 1uF/50V; EAGLE-LTSPICE_C0402
EPD_C5: 0.1uF/50V; EAGLE-LTSPICE_C0402
IC1: BD5229G-TR; SOT95P280X125-5N
IC4: XC6220A331MR-G; SOT95P280X120-5N
J1: FH34SRJ-24S-0.5SH_99_; FH34SRJ24S05SH99
J2: SAMACSYS_PARTS_USB4110-GF-A; SAMACSYS_PARTS_USB4110GFA
J3: QWIIC_RIGHT_ANGLE; JST04_1MM_RA
J4: 112A-TAAR-R03_ATTEND; 112ATAARR03ATTEND
L1: 744043680IND_4828-WE-TPC_WRE; IND_4828-WE-TPC_WRE
PFMF.050.1: ESP32C6_VARISTORCN1812; ESP32C6_VARISTOR_CT/CN1812
Q1, Q2: 20V/4.2A/52mΩ/1.4W; ESP32_WROVER_SPARKFUN-DISCRETESEMI_SOT23-3
Q3: SI1308EDL-T1-GE3; SOT65P210X110-3N
R1, R1_PINH, R1_PINH1, R2_PINH, R2_PINH1, R4, R5, R6, R7, R8, R9, R10: 10k; ESP32_WROVER_EAGLE-LTSPICE_R0402
R1_BAT: 200; ESP32_WROVER_EAGLE-LTSPICE_R0402
R1_PWRUSB: 100k; ESP32_WROVER_EAGLE-LTSPICE_R0402
R2: 2.2; ESP32_WROVER_EAGLE-LTSPICE_R0402
R2-USB1, R2-USB2: 5K1; ESP32_WROVER_EAGLE-LTSPICE_R0402
R2_BAT: 2k; ESP32_WROVER_EAGLE-LTSPICE_R0402
R3: 0.47; ESP32_WROVER_EAGLE-LTSPICE_R0402
RESET_BUTTON: BUTTON_CUSYOMV1; MYBUTTON
R_BOOT: 10k; ESP32_WROVER_EAGLE-LTSPICE_R0402
R_CAPACITOR: 15; ESP32_WROVER_EAGLE-LTSPICE_R0402
R_CHANGE: 10k; ESP32_WROVER_EAGLE-LTSPICE_R0402
R_CL1: 10k; ESP32_WROVER_EAGLE-LTSPICE_R0402
R_RESET: 10k; ESP32_WROVER_EAGLE-LTSPICE_R0402
SENSOR2: ESP32_WROVER_BME680_BME680; ESP32_WROVER_BME680_PSON80P300X300X100-8N
SJ1: SJ
TP1, TP2, TP3, TP4, TP5, TP6, TP7, TP8, TP9, TP10, TP11, TP12, TP13, TP14, TP15, TP16, TP17: TPTP20R; TP20R
U1: W25Q512JVEIQ; SON127P600X800X80-9N
U2: ESP32-C6-WROOM-1-N8; XCVR_ESP32-C6-WROOM-1-N8
U3: DS3231SN#; SOIC127P1032X265-16N
U4: MAX17048G+T10; SON50P200X200X80-9N
U5: ESP32_WROVER_SPARKFUN-IC-POWER_MCP73831; ESP32_WROVER_SPARKFUN-IC-POWER_SOT23-5

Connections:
3V3: C1_BAT2.1, C3.+, C9.1, D7.2 (ANODE), IC1.2 (VDD), IC4.5 (VOUT), J3.2, J4.P4 (VDD), Q2.3 (D), R1.2, R1_PINH1.2, R2_PINH1.2, R5.2, R6.2, R7.2, R8.2, R9.2, R10.2, R_BOOT.1, R_CHANGE.1, R_CL1.2, R_RESET.1, TP16.TP, U1.3 (!WP!(IO2)), U1.7 (!HOLD!/!RESET!(IO3)), U1.8 (VCC), U2.2 (3V3), U3.2 (VCC)
32KHZ: R2_PINH1.1, U2.9 (IO1), U3.1 (32KHZ)
DN: D1.4 (I/O2_2), J2.A7, J2.B7
DP: D1.6 (I/O1_2), J2.A6, J2.B6
EPD_3V3: C7.1, EPD_C5.1, J1.15, J1.16, L1.2, Q2.2 (S), TP17.TP
EPD_3V3_C: Q2.1 (G), R_CL1.1, TP13.TP, U2.18 (IO20)
EPD_BUSY: J1.9, TP9.TP, U2.26 (IO3)
EPD_CS: D6.2, J1.12, R9.1, TP10.TP, U2.11 (IO10)
EPD_DC: J1.11, TP11.TP, U2.5 (IO5)
EPD_RST: J1.10, TP12.TP, U2.21 (IO23)
FLASH_CS: D9.2, R5.1, U1.1 (!CS), U2.12 (IO11)
GDR: J1.2, Q3.1 (G), R4.2
GND: BOOT_BUTTON.1, BOOT_BUTTON.2, C1.2, C1_BAT.2, C1_BAT1.2, C1_BAT2.2, C2.2, C2_BAT.2, C3.-, C4_USB.2, C5.2, C5_USB.2, C6.2, C7.2, C8.2, C9.2, C10.2, C10_SUPERCAP.1, CHANGE_BUTTON.1, CHANGE_BUTTON.2, C_DELAY.2, D1.2 (GND), D3.1 (K), D6.1, D8.1, D9.1, D10.1, D11.1, D12.1, EPD_C1.2, EPD_C2.2, EPD_C5.2, EPD_C6.2, EPD_C7.2, EPD_C8.2, EPD_C9.2, EPD_C10.2, EPD_C11.2, EPD_C12.2, IC1.3 (GND), IC4.2 (VSS), J1.8, J1.17, J1.MP1, J1.MP2, J2.A1, J2.A12, J2.B1, J2.B12, J2.MP1, J2.MP2, J2.MP3, J2.MP4, J3.1, J4.G1 (GND_1), J4.G2 (GND_2), J4.G3 (GND_3), J4.G4 (GND_4), J4.P6 (VSS), R1_PWRUSB.1, R2.1, R2-USB1.1, R2-USB2.2, R2_BAT.1, R4.1, RESET_BUTTON.1, RESET_BUTTON.2, SENSOR2.1 (GND), SENSOR2.5 (SDO), SENSOR2.7 (GND), SJ1.1, TP4.TP, TP5.TP, U1.4 (GND), U1.9 (EXP), U2.1 (GND), U2.28 (GND), U2.29_1 (GND), U2.29_2 (GND), U2.29_3 (GND), U2.29_4 (GND), U2.29_5 (GND), U2.29_6 (GND), U2.29_7 (GND), U2.29_8 (GND), U2.29_9 (GND), U3.13 (GND), U4.1 (CTG), U4.4 (GND), U4.6 (QSTRT), U4.9 (EP), U5.2 (VSS)
GPIO8: R1.1, U2.10 (IO8)
I2C_PW: C1.1, C2.1, R1_PINH.2, R2_PINH.2, SENSOR2.2 (CSB), SENSOR2.6 (VDDIO), SENSOR2.8 (VDD), U2.17 (IO19)
INT_RTC: R1_PINH1.1, TP15.TP, U2.8 (IO0), U3.3 (SQW/!INT)
IO/BOOT: BOOT_BUTTON.3, BOOT_BUTTON.4, C6.1, R_BOOT.2, U2.15 (IO9)
IO/CHANGE: C10.1, CHANGE_BUTTON.3, CHANGE_BUTTON.4, R_CHANGE.2, U2.23 (IO15)
MISO: D12.2, J4.P7 (DAT0), R8.1, TP6.TP, U1.2 (DO(IO1)), U2.27 (IO2)
MOSI: D11.2, J1.14, J4.P3 (CMD), R7.1, TP7.TP, U1.5 (DI(IO0)), U2.7 (IO7)
unnamed: D7.1 (CATHODE), R_CAPACITOR.2
unnamed: J2.A5, R2-USB1.2
unnamed: J2.B5, R2-USB2.1
unnamed: C1_BAT1.1, D2.1 (CATHODE), IC4.1 (VIN), IC4.3 (CE), Q1.2 (S)
unnamed: C4.1, D3.2 (A), D4.1 (K)
unnamed: R2_BAT.2, U5.5 (PROG)
unnamed: EPD_C12.1, J1.24
unnamed: R1_BAT.1, U5.1 (STAT)
unnamed: CHG_LED.C, R1_BAT.2
unnamed: C_DELAY.1, IC1.5 (CT)
unnamed: EPD_C1.1, J1.4
unnamed: EPD_C2.1, J1.5
unnamed: EPD_C6.1, J1.18
unnamed: EPD_C7.1, J1.19
unnamed: EPD_C8.1, J1.20
unnamed: EPD_C10.1, J1.22
PREVGH: D5.1 (K), EPD_C9.1, J1.21
PREVGL: D4.2 (A), EPD_C11.1, J1.23
RESE: J1.3, Q3.2 (S), R3.2
RESE': R2.2, R3.1, SJ1.2
RESET: C5.1, IC1.1 (VOUT), RESET_BUTTON.3, RESET_BUTTON.4, R_RESET.2, U2.3 (EN)
RTC_RST: U2.16 (IO18), U3.4 (!RST)
RX: TP2.TP, U2.24 (RXD0/GPIO17)
SCK: D10.2, J1.13, J4.P5 (CLK), R6.1, TP8.TP, U1.6 (CLK), U2.6 (IO6)
SCL: J3.4, R2_PINH.1, SENSOR2.4 (SCK), U2.20 (IO22), U3.16 (SCL), U4.7 (SCL)
SDA: J3.3, R1_PINH.1, SENSOR2.3 (SDI), U2.19 (IO21), U3.15 (SDA), U4.8 (SDA)
SRC: C4.2, D5.2 (A), L1.1, Q3.3 (D)
SS_SD: D8.2, J4.P2 (CD/DAT3), R10.1, U2.4 (IO4)
TX: TP1.TP, U2.25 (TXD0/GPIO16)
USB_D+: D1.1 (I/O1_1), U2.14 (IO13)
USB_D-: D1.3 (I/O2_1), U2.13 (IO12)
VBAT: C2_BAT.1, Q1.3 (D), TP3.TP, U4.2 (CELL), U4.3 (VDD), U5.3 (VBAT)
VBUS: C1_BAT.1, C4_USB.1, C5_USB.1, CHG_LED.A, D1.5 (VBUS), D2.2 (ANODE), PFMF.050.1.2, Q1.1 (G), R1_PWRUSB.2, TP14.TP, U5.4 (VIN)
VRTC: C8.1, C10_SUPERCAP.2, R_CAPACITOR.1, U3.14 (VBAT)
VUSB: J2.A4, J2.A9, J2.B4, J2.B9, PFMF.050.1.1

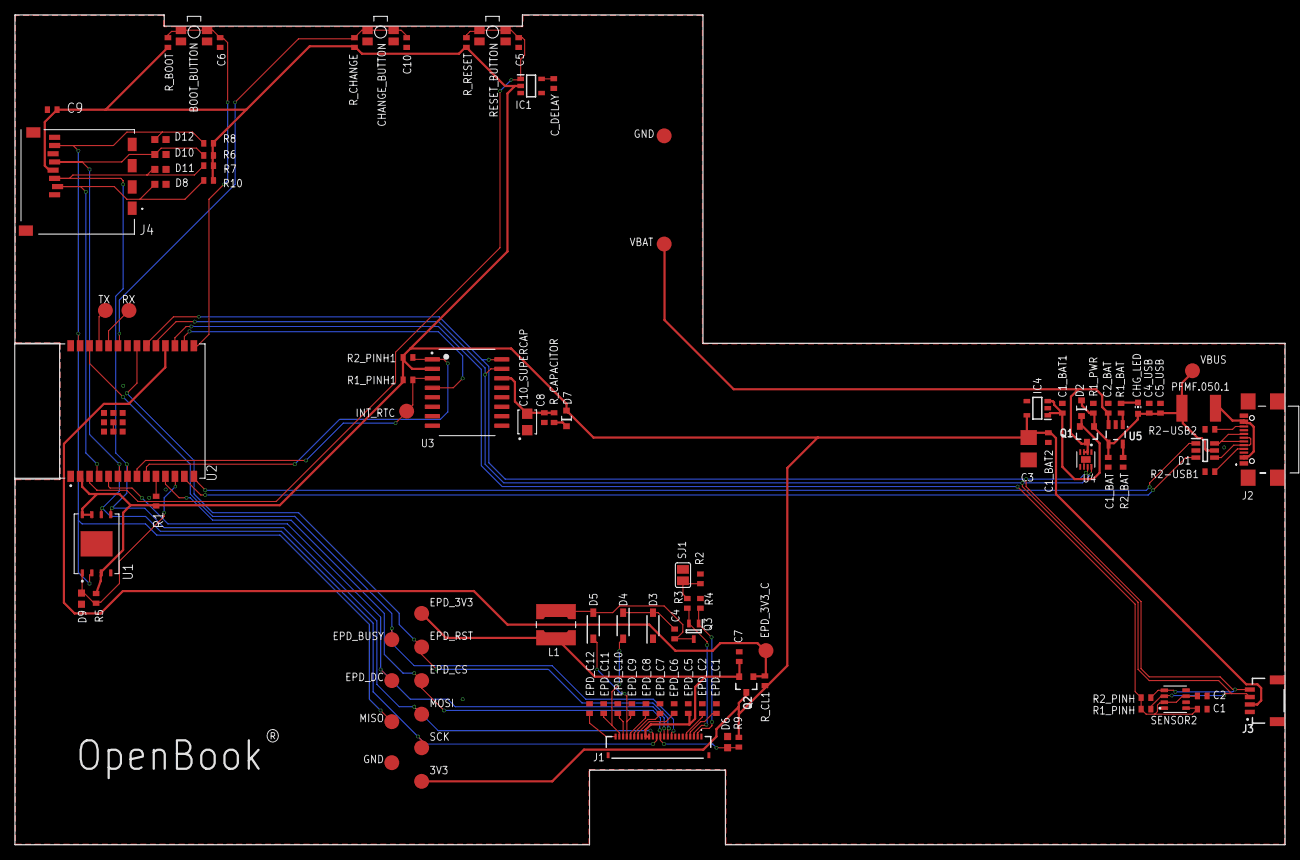
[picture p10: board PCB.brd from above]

Board: 2 copper layers, 170.2 x 111.2 mm, 103 parts (0 on the bottom side), 55 nets.

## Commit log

2025-04-06 Added project files
    [Bill-of-Materials.csv, PCB.brd, Pick-and-Place.csv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]
2025-04-16 Update PCB design with Via Stitching + board dimension
    [PCB.brd]

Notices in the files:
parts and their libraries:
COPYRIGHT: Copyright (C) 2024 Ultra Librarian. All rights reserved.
